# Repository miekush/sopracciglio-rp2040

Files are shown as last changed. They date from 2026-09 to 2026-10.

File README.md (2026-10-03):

# Sopracciglio RP2040
Raspberry Pi RP2040 based Sopracciglio Board for use with 2026 Open Sauce Badge

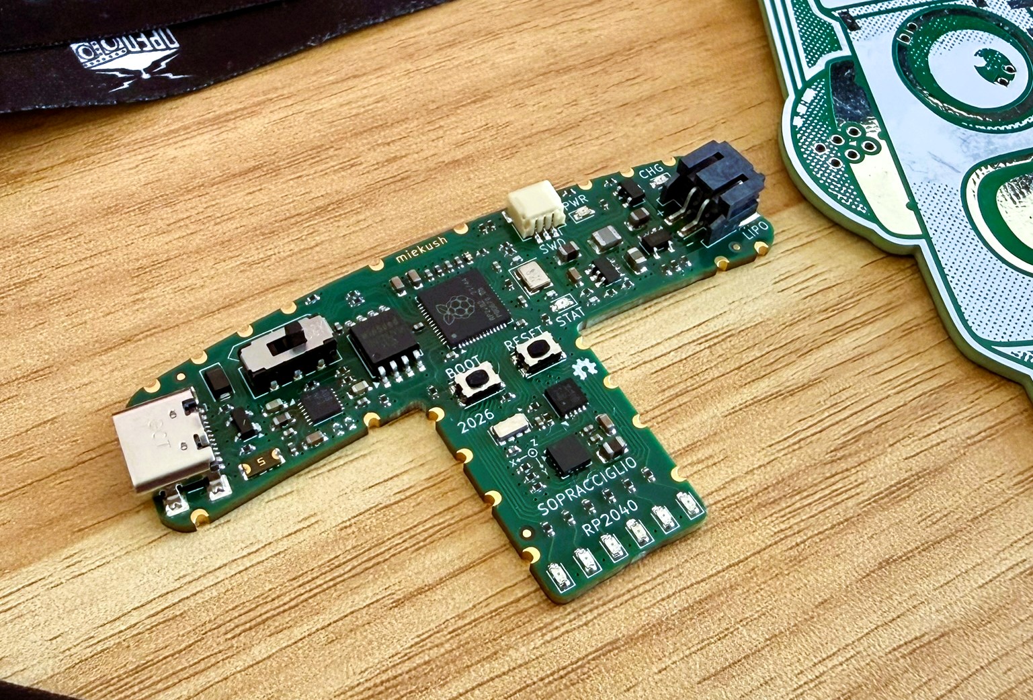
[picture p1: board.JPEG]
Board Image


# Schematic
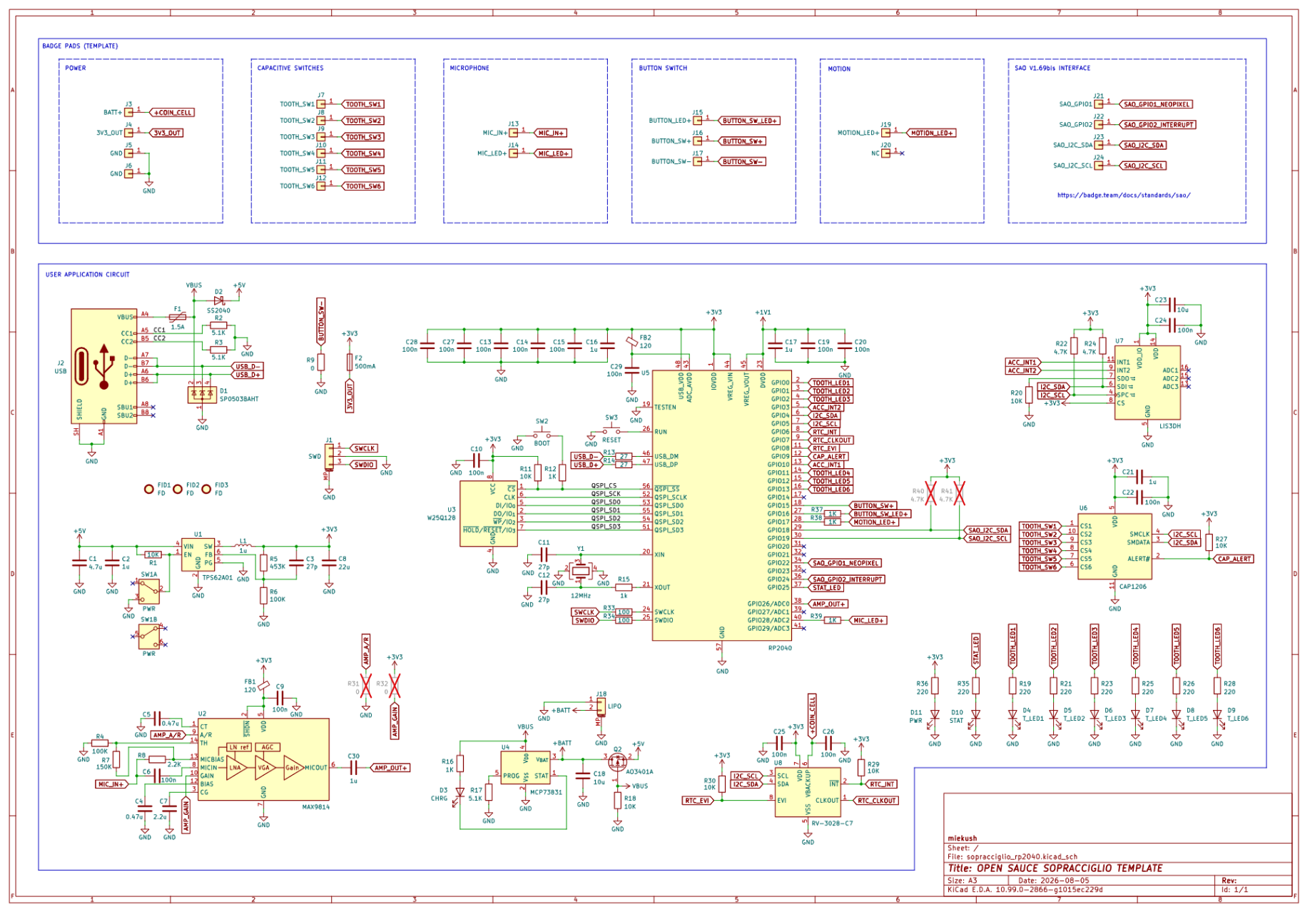
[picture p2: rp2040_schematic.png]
Schematic


# Layout
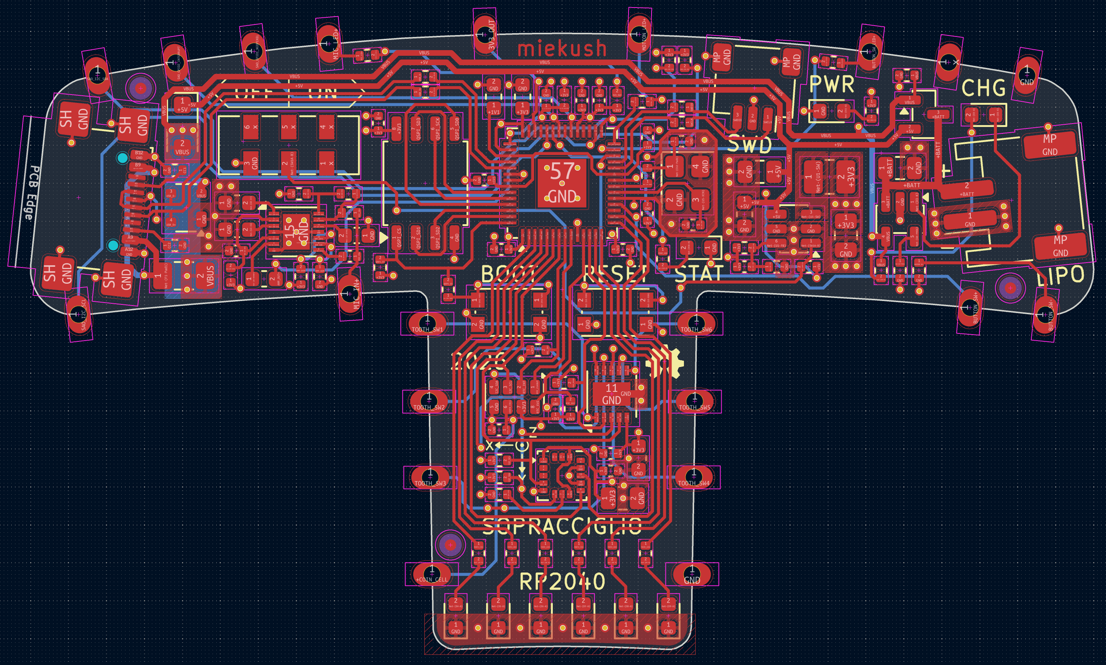
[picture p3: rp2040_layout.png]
Board Layout


# Installation

1. Clone repo to a folder of your choice
2. Open the project in KiCad V10.99
3. "Save As" with the name of your project
4. Enjoy! :)

# License

miekush supports the open source hardware community by sharing hardware design files freely on GitHub!

Designed by Mike Kushnerik (miekush)

Licensed under [Creative Commons Attribution-ShareAlike CC BY-SA 4.0](http://creativecommons.org/licenses/by-sa/4.0/)

All text above must be included in any redistribution!

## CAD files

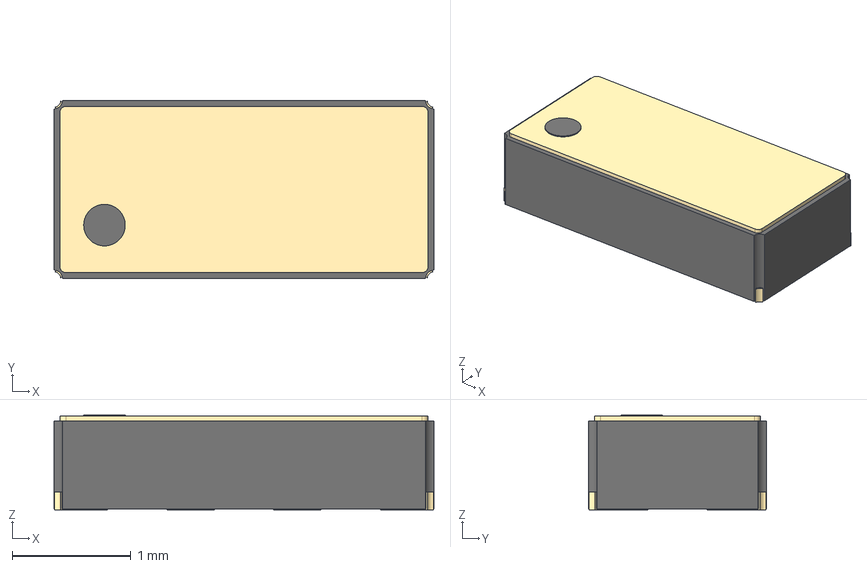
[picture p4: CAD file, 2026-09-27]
3D Models/RV-3028-C7.stp
3.20 x 1.50 x 0.8 mm
Rect2
Rect3
Rect4
Rect5
Terminal

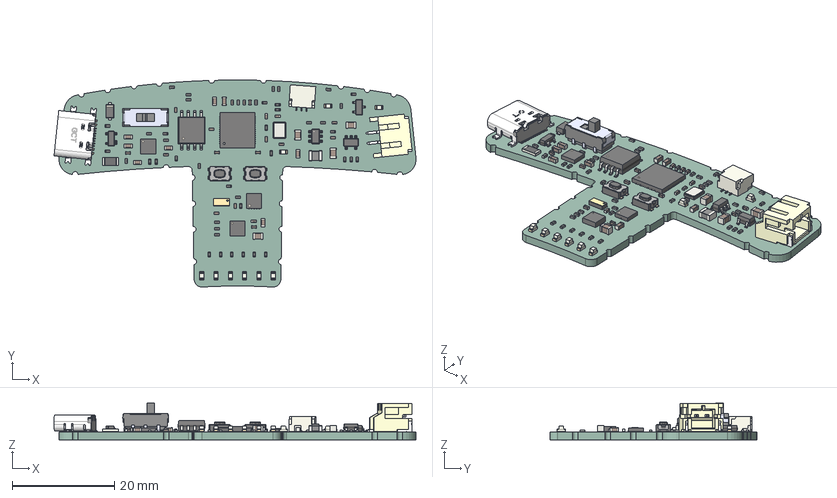
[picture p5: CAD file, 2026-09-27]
sopracciglio_rp2040.step
70.9 x 40.6 x 7.19 mm
C_0402_1005Metric x 19
R_0402_1005Metric x 41
LED_0603_1608Metric x 9
C_0603_1608Metric x 8
L_0402_1005Metric x 2
SOT-23
USB4110-GF-A_revB(1) MF
DFN-10-1EP_3x3mm_Pitch0.5mm
Crystal_SMD_Abracon_ABM8G-4Pin_3.2x2.5mm
S2B-PH-SM4-TB(LF)(SN)
C_0805_2012Metric x 4
SW_Push_1P1T_NO_CK_KMR2 x 2
JST_SH_SM03B-SRSS-TB_1x03-1MP_P1.00mm_Horizontal
LGA_16_3x3mm_P05mm_LayoutBorder3x5y
SOIC-8_5.3x5.3mm_P1.27mm
JS202011JCQN
SOT-23-6
Rect2
Rect3
Rect4
Rect5
Terminal
SOT-23-5
SOT-143
L_1008_2520Metric
DFN_14_1EP_3x3mm_Pitch04mm
D_SOD_123F
Fuse_1206_3216Metric
QFN-56-1EP_7x7mm_P0.4mm_EP3.2x3.2mm
sop3202_PCB

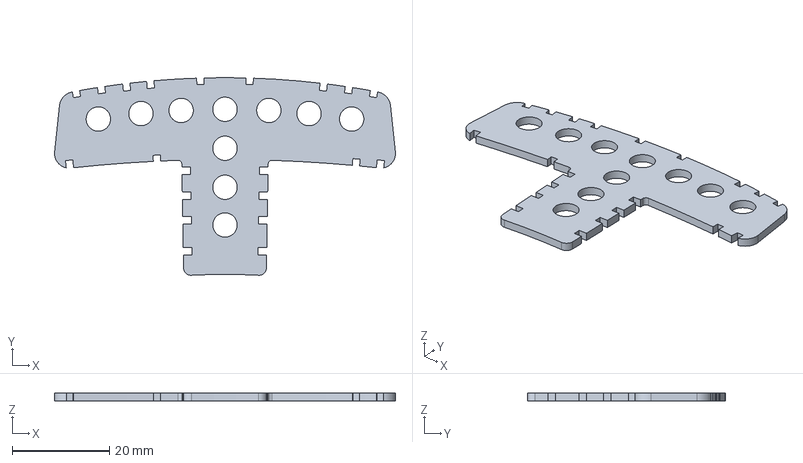
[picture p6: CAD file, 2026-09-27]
Board Outline/sopracciglio_outline.FCStd
70.0 x 40.6 x 1.60 mm

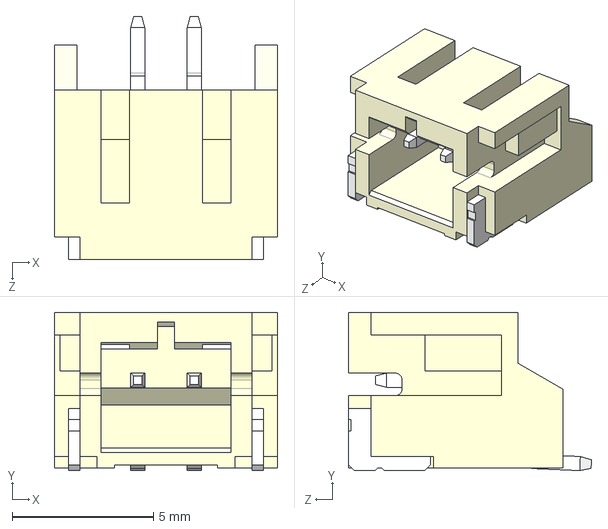
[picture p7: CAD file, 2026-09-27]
3D Models/S2B-PH-SM4-TB--3DModel-STEP-269445.STEP
7.90 x 5.60 x 8.60 mm

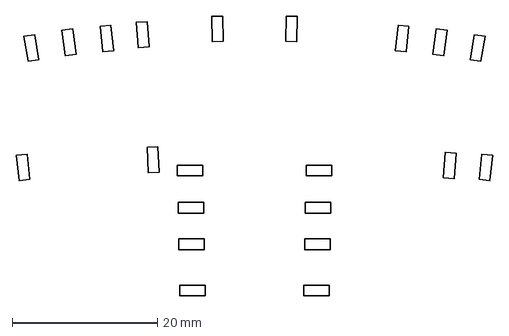
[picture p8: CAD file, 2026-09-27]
Board Outline/sopracciglio-pad_locations.dxf
65.5 x 38.5 mm

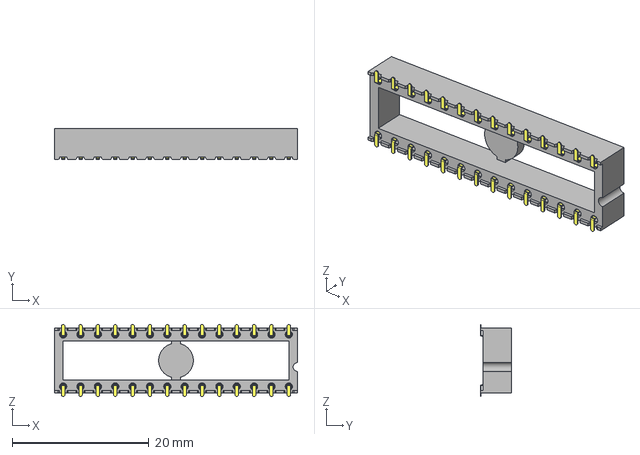
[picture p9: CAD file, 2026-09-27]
3D Models/ICF-328-T-O-TR.stp
35.6 x 4.57 x 10.5 mm
ICF-328-T-O-TR_t
ICF-328-O_p

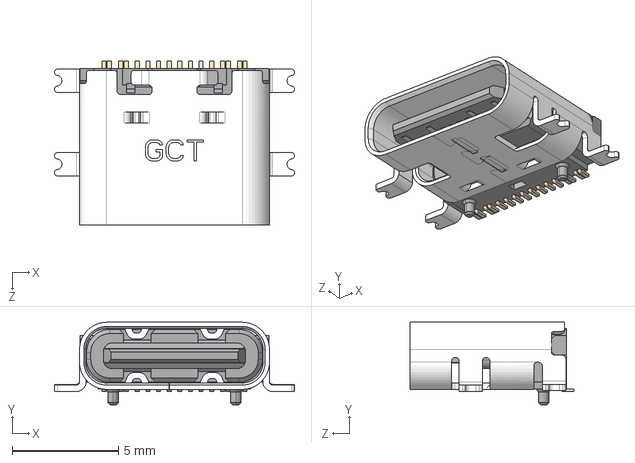
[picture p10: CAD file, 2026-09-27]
3D Models/USB4110GFA--3DModel-STEP-269445.STEP
11.3 x 3.89 x 7.70 mm

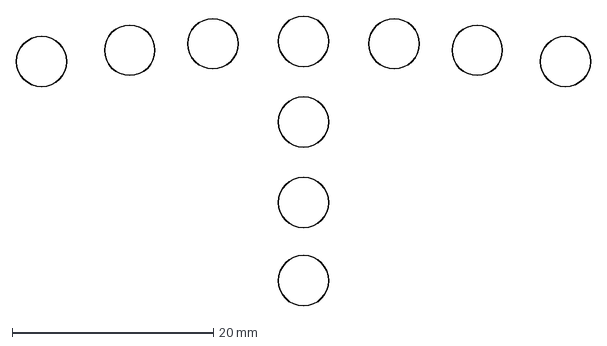
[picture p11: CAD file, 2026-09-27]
Board Outline/sopracciglio-bolts.dxf
57.0 x 28.8 mm

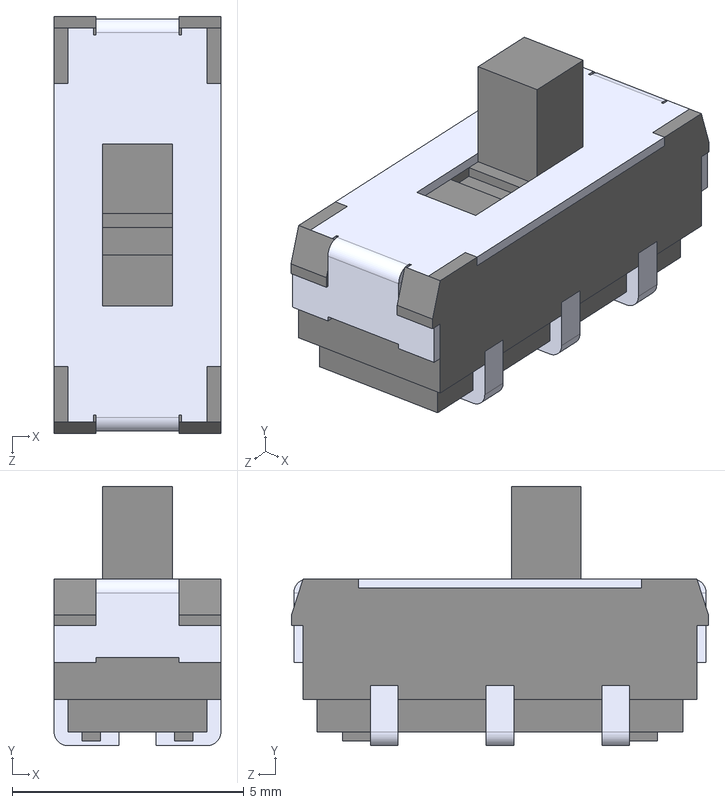
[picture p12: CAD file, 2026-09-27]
3D Models/JS202011JCQN--3DModel-STEP-1.STEP
3.60 x 5.60 x 9.00 mm

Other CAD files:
Board Outline/sopracciglio-outline.dxf

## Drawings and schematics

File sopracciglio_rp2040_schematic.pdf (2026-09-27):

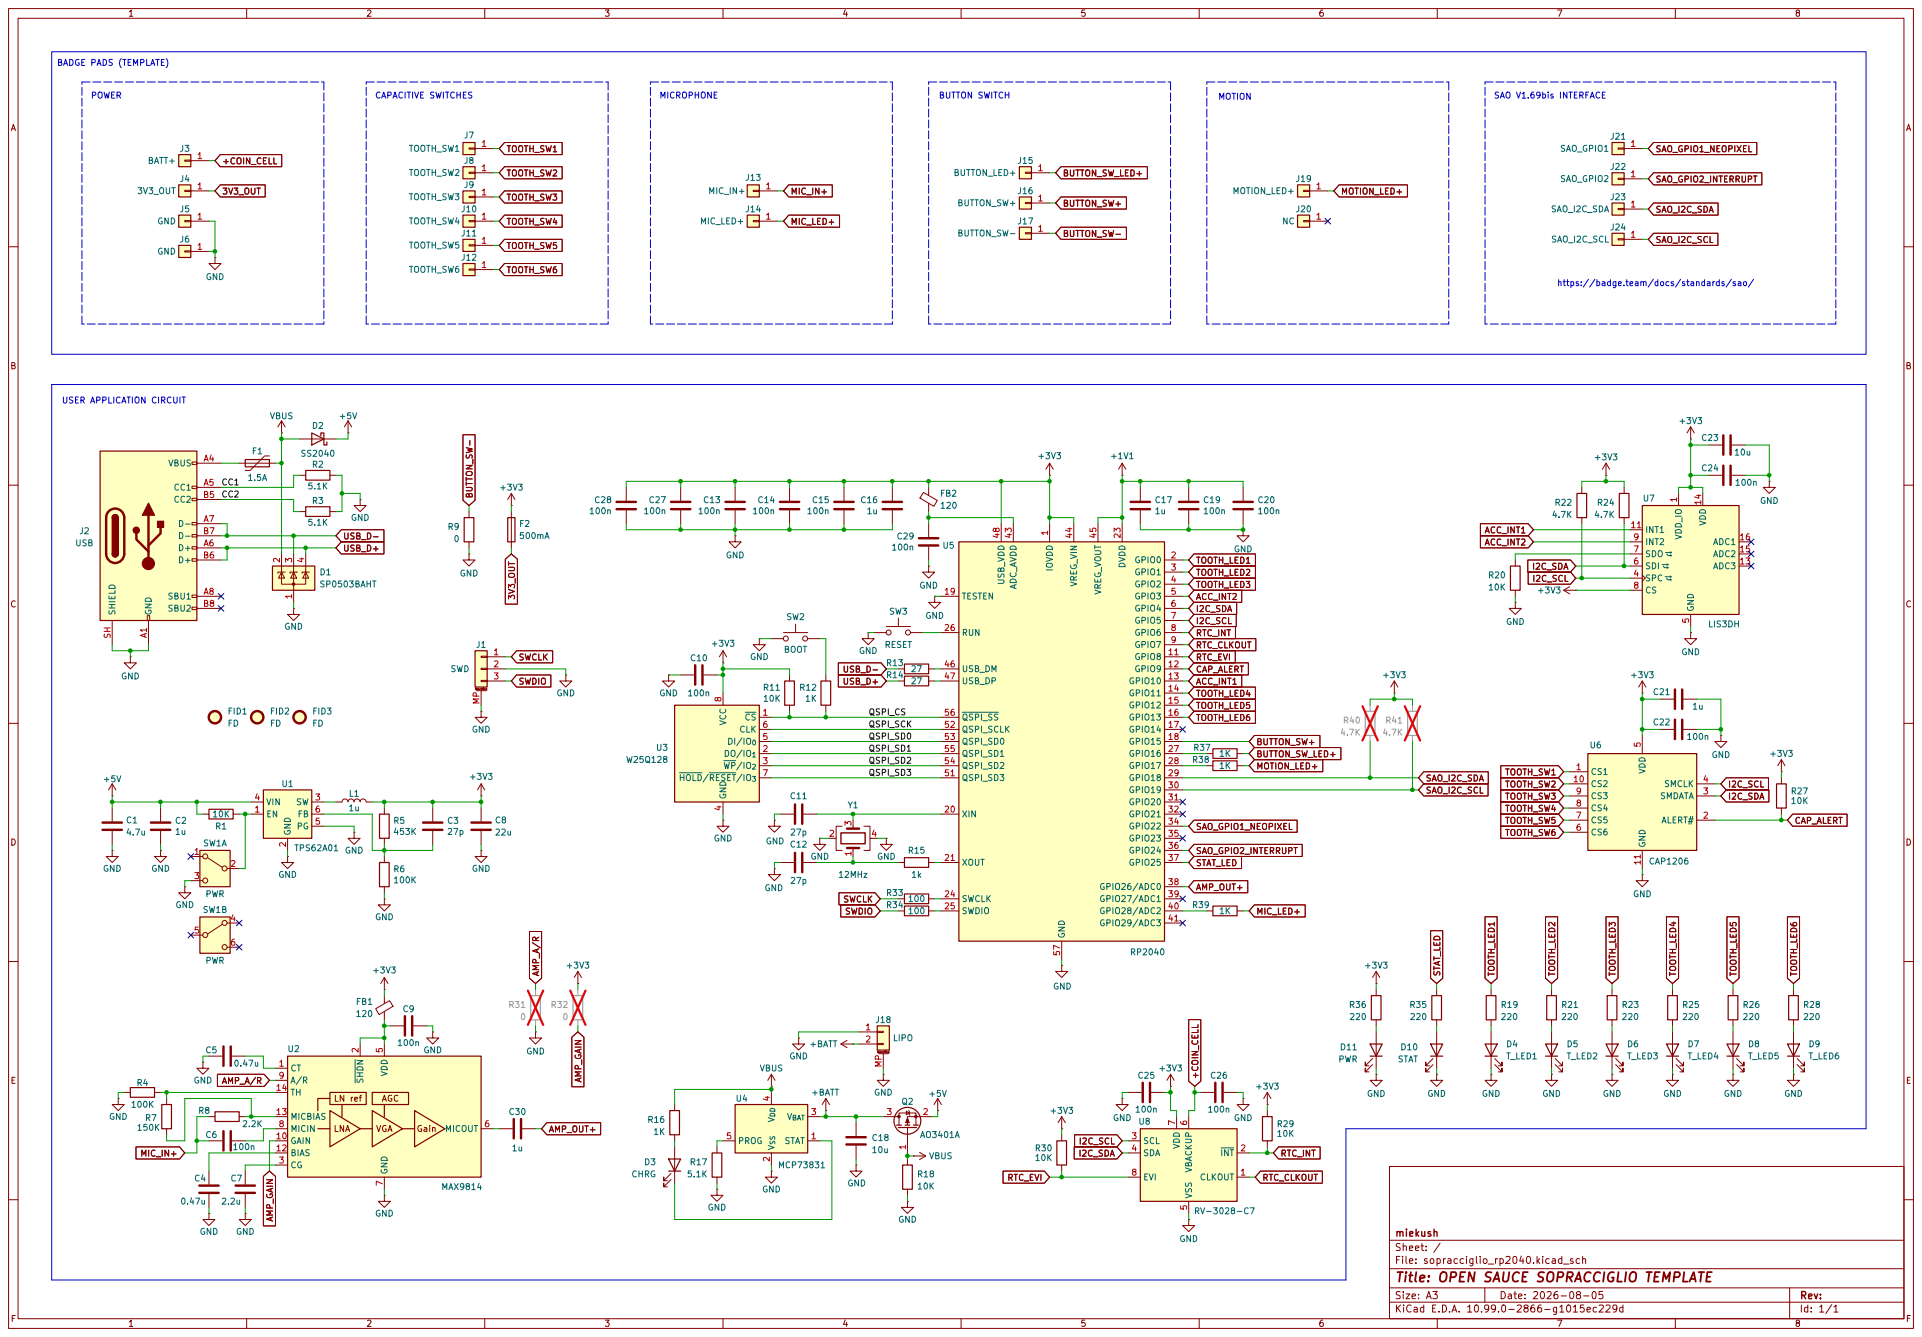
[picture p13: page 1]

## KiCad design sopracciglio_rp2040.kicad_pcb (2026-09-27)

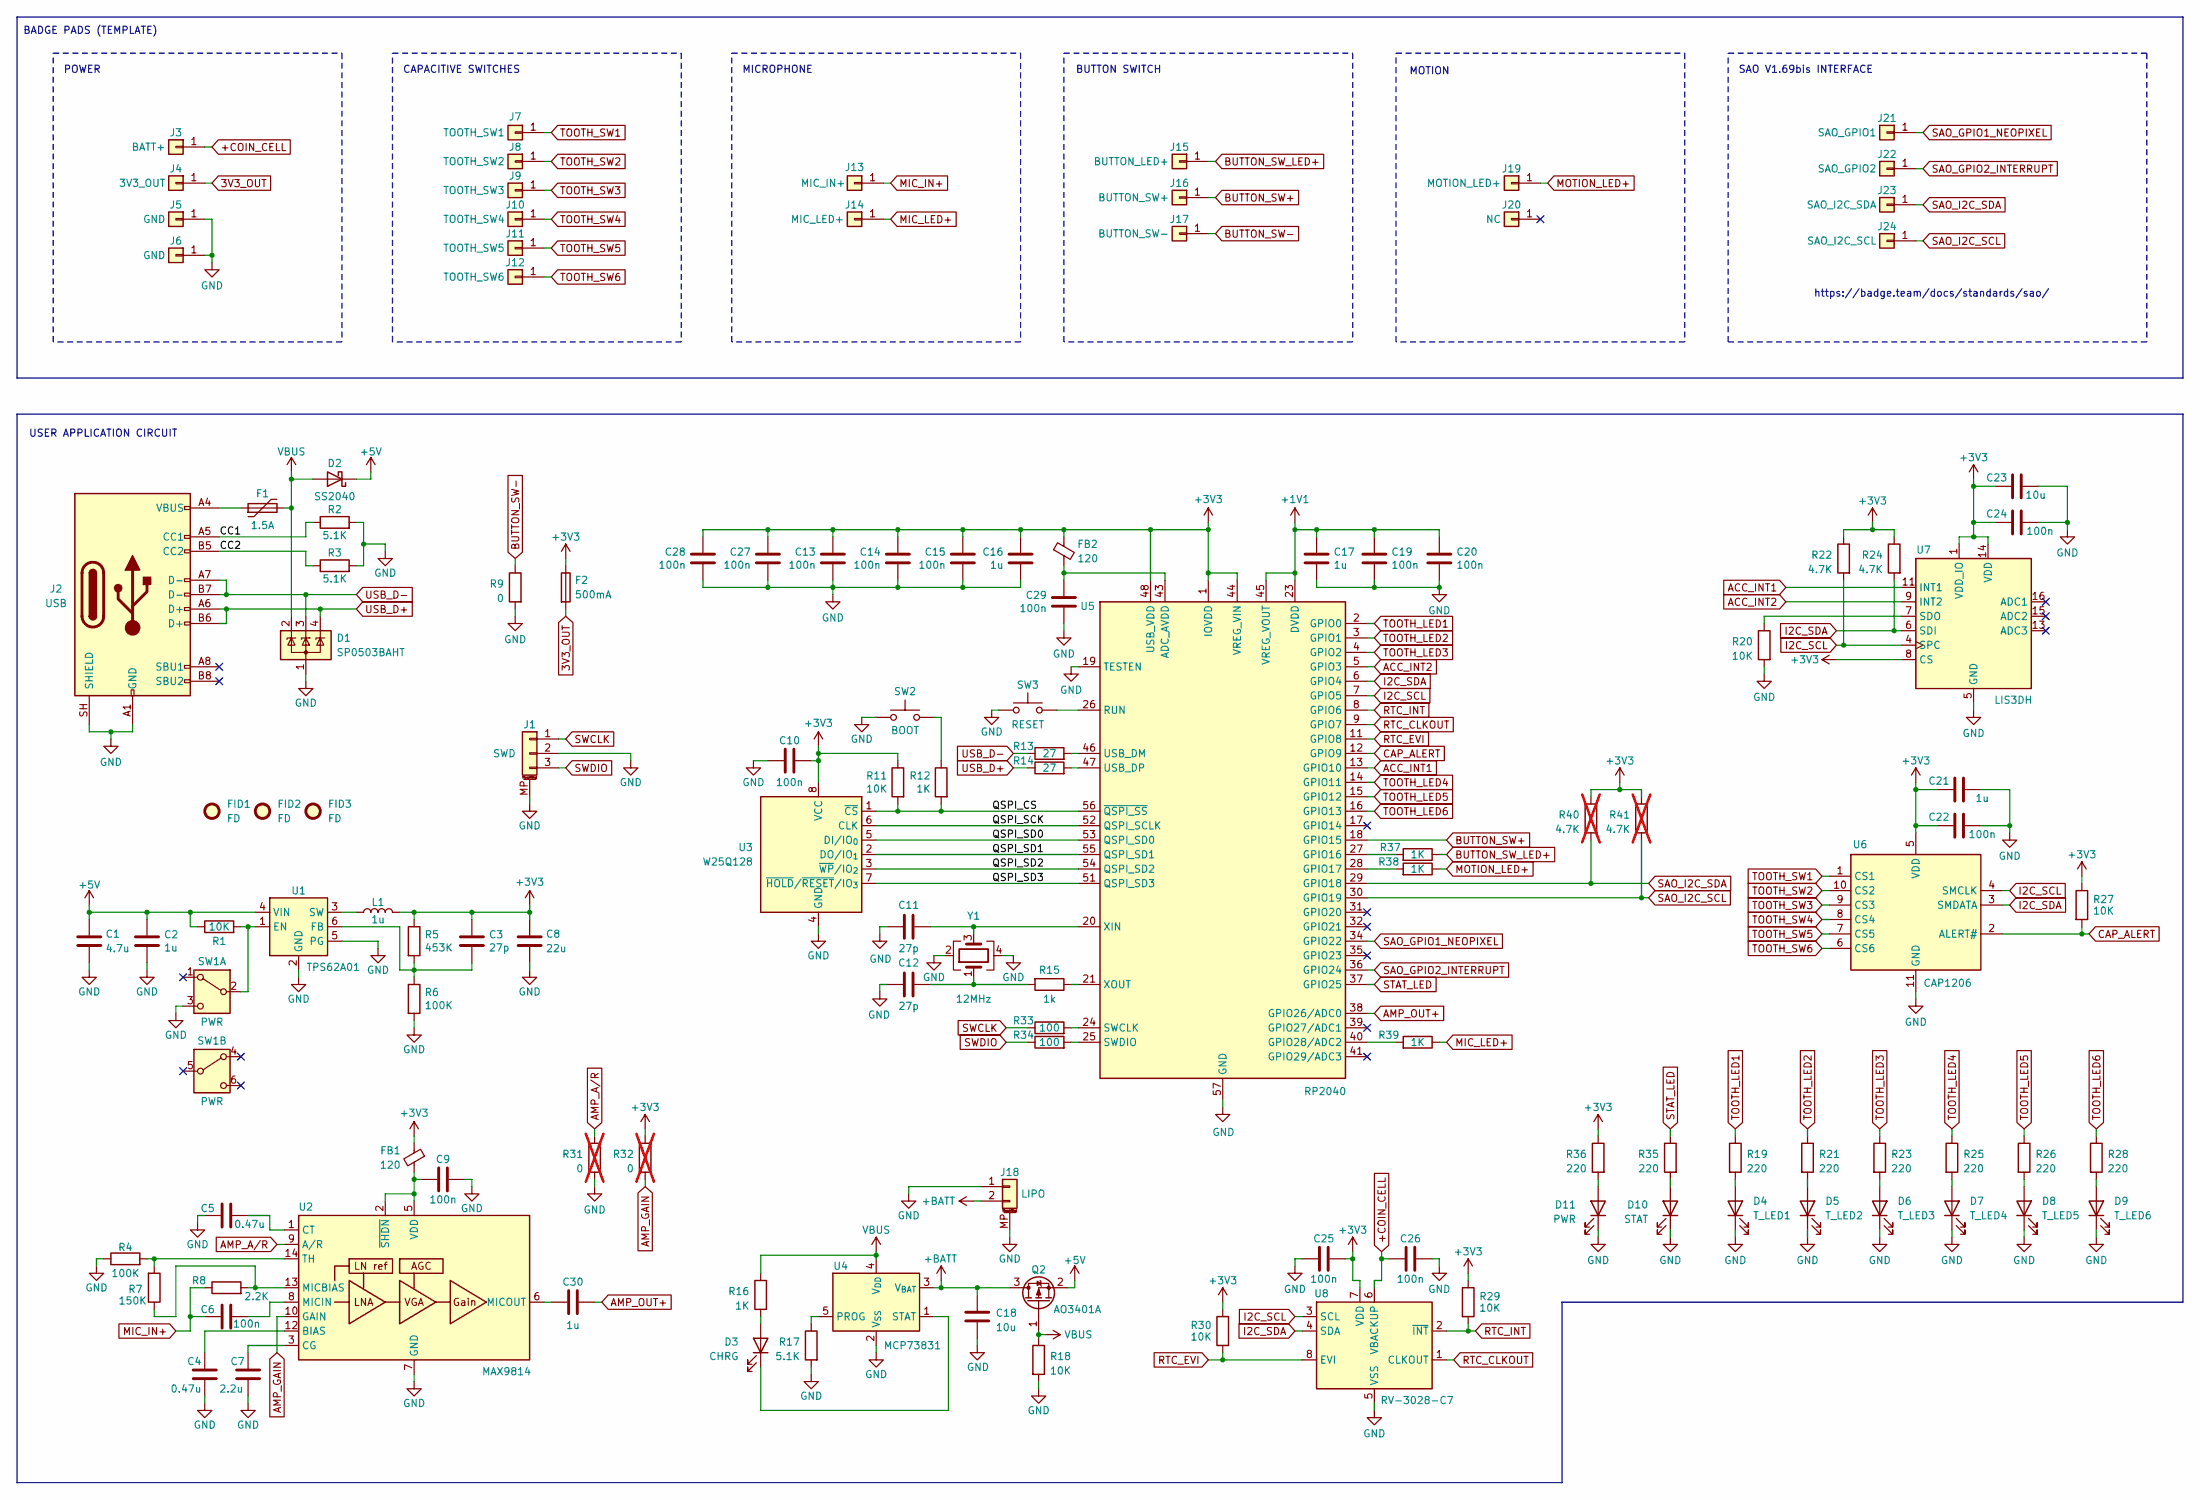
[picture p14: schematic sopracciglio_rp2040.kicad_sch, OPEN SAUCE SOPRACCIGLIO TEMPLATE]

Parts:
C1: 4.7u; C_0805_2012Metric
C2, C16, C17, C21, C30: 1u; C_0603_1608Metric
C3, C11, C12: 27p; C_0402_1005Metric
C4, C5: 0.47u; C_0603_1608Metric
C6, C9, C10, C13, C14, C15, C19, C20, C22, C24, C25, C26, C27, C28, C29: 100n; C_0402_1005Metric
C7: 2.2u; C_0603_1608Metric
C8: 22u; C_0805_2012Metric
C18, C23: 10u; C_0805_2012Metric
D1: SP0503BAHT; SOT-143
D2: SS2040; D_SOD-123F
D3: CHRG; LED_0603_1608Metric
D4: T_LED1; LED_0603_1608Metric
D5: T_LED2; LED_0603_1608Metric
D6: T_LED3; LED_0603_1608Metric
D7: T_LED4; LED_0603_1608Metric
D8: T_LED5; LED_0603_1608Metric
D9: T_LED6; LED_0603_1608Metric
D10: STAT; LED_0603_1608Metric
D11: PWR; LED_0603_1608Metric
F1: 1.5A; Fuse_1206_3216Metric
F2: 500mA; Fuse_0402_1005Metric
FB1, FB2: 120; L_0402_1005Metric
FID1, FID2, FID3: FD; Fiducial_0.75mm_Mask1.5mm
J1: SWD; JST_SH_SM03B-SRSS-TB_1x03-1MP_P1.00mm_Horizontal
J2: USB; USB_C_Receptacle_GCT_USB4110
J3: BATT+; castellated_pad
J4: 3V3_OUT; castellated_pad
J5, J6: GND; castellated_pad
J7: TOOTH_SW1; castellated_pad
J8: TOOTH_SW2; castellated_pad
J9: TOOTH_SW3; castellated_pad
J10: TOOTH_SW4; castellated_pad
J11: TOOTH_SW5; castellated_pad
J12: TOOTH_SW6; castellated_pad
J13: MIC_IN+; castellated_pad
J14: MIC_LED+; castellated_pad
J15: BUTTON_LED+; castellated_pad
J16: BUTTON_SW+; castellated_pad
J17: BUTTON_SW-; castellated_pad
J18: LIPO; JST_PH_S2B-PH-SM4-TB_1x02-1MP_P2.00mm_Horizontal
J19: MOTION_LED+; castellated_pad
J20: NC; castellated_pad
J21: SAO_GPIO1; castellated_pad
J22: SAO_GPIO2; castellated_pad
J23: SAO_I2C_SDA; castellated_pad
J24: SAO_I2C_SCL; castellated_pad
L1: 1u; L_1008_2520Metric
Q2: AO3401A; SOT-23
R1, R11, R18, R20, R27, R29, R30: 10K; R_0402_1005Metric
R2, R3, R17: 5.1K; R_0402_1005Metric
R4, R6: 100K; R_0402_1005Metric
R5: 453K; R_0402_1005Metric
R7: 150K; R_0402_1005Metric
R8: 2.2K; R_0402_1005Metric
R9: 0; R_0402_1005Metric
R12, R16, R37, R38, R39: 1K; R_0402_1005Metric
R13, R14: 27; R_0402_1005Metric
R15: 1k; R_0402_1005Metric
R19, R21, R23, R25, R26, R28, R35, R36: 220; R_0402_1005Metric
R22, R24: 4.7K; R_0402_1005Metric
R31, R32: 0; R_0402_1005Metric; not fitted
R33, R34: 100; R_0402_1005Metric
R40, R41: 4.7K; R_0402_1005Metric; not fitted
SW1: PWR; SW_DPDT_CK_JS202011JCQN
SW2: BOOT; SW_Push_1P1T_NO_CK_KMR2
SW3: RESET; SW_Push_1P1T_NO_CK_KMR2
U1: TPS62A01; SOT-23-6
U2: MAX9814; DFN-14-1EP_3x3mm_P0.4mm_EP1.78x2.35mm
U3: W25Q128; SOIC-8_5.3x5.3mm_P1.27mm
U4: MCP73831; SOT-23-5
U5: RP2040; QFN-56-1EP_7x7mm_P0.4mm_EP3.2x3.2mm
U6: CAP1206; DFN-10-1EP_3x3mm_P0.5mm_EP1.55x2.48mm
U7: LIS3DH; LGA-16_3x3mm_P0.5mm_LayoutBorder3x5y
U8: RV-3028-C7; MicroCrystal_C7_SON-8_1.5x3.2mm_P0.9mm
Y1: 12MHz; Crystal_SMD_Abracon_ABM8G-4Pin_3.2x2.5mm

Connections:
3V3_OUT: F2.2, J4.1 (Pin_1_1)
+1V1: C17.1, C19.1, C20.1, U5.23 (DVDD), U5.45 (VREG_VOUT), U5.50 (DVDD)
+3V3: C3.1, C8.1, C10.1, C13.1, C14.1, C15.1, C16.1, C21.1, C22.1, C23.1, C24.1, C25.1, C27.1, C28.1, F2.1, FB1.1, FB2.1, L1.2, R5.1, R11.1, R22.1, R24.1, R27.1, R29.1, R30.1, R32.1, R36.1, R40.1, R41.1, U3.8 (VCC), U5.1 (IOVDD), U5.10 (IOVDD), U5.22 (IOVDD), U5.33 (IOVDD), U5.42 (IOVDD), U5.44 (VREG_VIN), U5.48 (USB_VDD), U5.49 (IOVDD), U6.5 (VDD), U7.1 (VDD_IO), U7.8 (CS), U7.14 (VDD), U8.7 (VDD)
+5V: C1.1, C2.1, D2.1 (K), Q2.2 (S), R1.1, U1.4 (VIN)
+BATT: C18.1, J18.2, Q2.3 (D), U4.3 (V_{BAT})
+COIN_CELL: C26.1, J3.1 (Pin_1_1), U8.6 (VBACKUP)
/CC1: J2.A5 (CC1), R2.1
/CC2: J2.B5 (CC2), R3.1
/QSPI_CS: R11.2, R12.2, U3.1 (~CS), U5.56 (~QSPI_SS)
/QSPI_SCK: U3.6 (CLK), U5.52 (QSPI_SCLK)
/QSPI_SD0: U3.5 (DI/IO_{0}), U5.53 (QSPI_SD0)
/QSPI_SD1: U3.2 (DO/IO_{1}), U5.55 (QSPI_SD1)
/QSPI_SD2: U3.3 (~WP/IO_{2}), U5.54 (QSPI_SD2)
/QSPI_SD3: U3.7 (~HOLD/~RESET/IO_{3}), U5.51 (QSPI_SD3)
ACC_INT1: U5.13 (GPIO10), U7.11 (INT1)
ACC_INT2: U5.5 (GPIO3), U7.9 (INT2)
AMP_A/R: R31.1, U2.9 (A/R)
AMP_GAIN: R32.2, U2.10 (GAIN)
AMP_OUT+: C30.2, U5.38 (GPIO26/ADC0)
BUTTON_SW+: J16.1 (Pin_1_1), U5.18 (GPIO15)
BUTTON_SW-: J17.1 (Pin_1_1), R9.1
BUTTON_SW_LED+: J15.1 (Pin_1_1), R37.1
CAP_ALERT: R27.2, U5.12 (GPIO9), U6.2 (ALERT#)
GND: C1.2, C2.2, C4.1, C5.1, C7.1, C8.2, C9.2, C10.2, C11.2, C12.2, C13.2, C14.2, C15.2, C16.2, C17.2, C18.2, C19.2, C20.2, C21.2, C22.2, C23.2, C24.2, C25.2, C26.2, C27.2, C28.2, C29.2, D1.1 (A), D4.1 (K), D5.1 (K), D6.1 (K), D7.1 (K), D8.1 (K), D9.1 (K), D10.1 (K), D11.1 (K), J1.2, J1.MP (MountPin), J2.A1 (GND), J2.A12 (GND), J2.B1 (GND), J2.B12 (GND), J2.SH (SHIELD), J5.1 (Pin_1_1), J6.1 (Pin_1_1), J18.1, J18.MP (MountPin), R2.2, R3.2, R4.1, R6.2, R9.2, R17.2, R18.2, R20.2, R31.2, SW1.3 (C), SW2.2, SW3.1, U1.2 (GND), U1.5 (PG), U2.4 (GND), U2.7 (GND), U2.11 (GND), U2.15 (GND), U3.4 (GND), U4.2 (V_{SS}), U5.19 (TESTEN), U5.57 (GND), U6.11 (GND), U7.5 (GND), U7.10 (GND), U7.12 (GND), U8.5 (VSS), Y1.2, Y1.4
I2C_SCL: R22.2, U5.7 (GPIO5), U6.4 (SMCLK), U7.4 (SPC), U8.3 (SCL)
I2C_SDA: R24.2, U5.6 (GPIO4), U6.3 (SMDATA), U7.6 (SDI), U8.4 (SDA)
MIC_IN+: C6.1, J13.1 (Pin_1_1), R8.1
MIC_LED+: J14.1 (Pin_1_1), R39.1
MOTION_LED+: J19.1 (Pin_1_1), R38.1
unnamed: C12.1, R15.2, Y1.1
unnamed: D3.2 (A), R16.2
unnamed: D3.1 (K), U4.1 (STAT)
unnamed: D4.2 (A), R19.2
unnamed: D5.2 (A), R21.2
unnamed: D6.2 (A), R23.2
unnamed: D7.2 (A), R25.2
unnamed: D8.2 (A), R26.2
unnamed: D9.2 (A), R28.2
unnamed: D10.2 (A), R35.2
unnamed: D11.2 (A), R36.2
unnamed: F1.1, J2.A4 (VBUS), J2.A9 (VBUS), J2.B4 (VBUS), J2.B9 (VBUS)
unnamed: R12.1, SW2.1
unnamed: R1.2, SW1.2 (B), U1.1 (EN)
unnamed: C3.2, R5.2, R6.1, U1.6 (FB)
unnamed: L1.1, U1.3 (SW)
unnamed: C4.2, U2.12 (BIAS)
unnamed: C7.2, U2.3 (CG)
unnamed: C5.2, U2.1 (CT)
unnamed: R7.1, R8.2, U2.13 (MICBIAS)
unnamed: C6.2, U2.8 (MICIN)
unnamed: C30.1, U2.6 (MICOUT)
unnamed: R4.2, R7.2, U2.14 (TH)
unnamed: C9.1, FB1.2, U2.2 (~SHDN), U2.5 (VDD)
unnamed: R17.1, U4.5 (PROG)
unnamed: C29.1, FB2.2, U5.43 (ADC_AVDD)
unnamed: R37.2, U5.27 (GPIO16)
unnamed: R38.2, U5.28 (GPIO17)
unnamed: R39.2, U5.40 (GPIO28/ADC2)
unnamed: SW3.2, U5.26 (RUN)
unnamed: R33.2, U5.24 (SWCLK)
unnamed: R34.2, U5.25 (SWDIO)
unnamed: R13.2, U5.46 (USB_DM)
unnamed: R14.2, U5.47 (USB_DP)
unnamed: C11.1, U5.20 (XIN), Y1.3
unnamed: R15.1, U5.21 (XOUT)
unnamed: R20.1, U7.7 (SDO)
RTC_CLKOUT: U5.9 (GPIO7), U8.1 (CLKOUT)
RTC_EVI: R30.2, U5.11 (GPIO8), U8.8 (EVI)
RTC_INT: R29.2, U5.8 (GPIO6), U8.2 (~INT)
SAO_GPIO1_NEOPIXEL: J21.1 (Pin_1_1), U5.34 (GPIO22)
SAO_GPIO2_INTERRUPT: J22.1 (Pin_1_1), U5.36 (GPIO24)
SAO_I2C_SCL: J24.1 (Pin_1_1), R41.2, U5.30 (GPIO19)
SAO_I2C_SDA: J23.1 (Pin_1_1), R40.2, U5.29 (GPIO18)
STAT_LED: R35.1, U5.37 (GPIO25)
SWCLK: J1.1, R33.1
SWDIO: J1.3, R34.1
TOOTH_LED1: R19.1, U5.2 (GPIO0)
TOOTH_LED2: R21.1, U5.3 (GPIO1)
TOOTH_LED3: R23.1, U5.4 (GPIO2)
TOOTH_LED4: R25.1, U5.14 (GPIO11)
TOOTH_LED5: R26.1, U5.15 (GPIO12)
TOOTH_LED6: R28.1, U5.16 (GPIO13)
TOOTH_SW1: J7.1 (Pin_1_1), U6.1 (CS1)
TOOTH_SW2: J8.1 (Pin_1_1), U6.10 (CS2)
TOOTH_SW3: J9.1 (Pin_1_1), U6.9 (CS3)
TOOTH_SW4: J10.1 (Pin_1_1), U6.8 (CS4)
TOOTH_SW5: J11.1 (Pin_1_1), U6.7 (CS5)
TOOTH_SW6: J12.1 (Pin_1_1), U6.6 (CS6)
USB_D+: D1.4 (K), J2.A6 (D+), J2.B6 (D+), R14.1
USB_D-: D1.3 (K), J2.A7 (D-), J2.B7 (D-), R13.1
VBUS: D1.2 (K), D2.2 (A), F1.2, Q2.1 (G), R16.1, R18.1, U4.4 (V_{DD})

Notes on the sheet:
SAO V1.69bis INTERFACE
https://badge.team/docs/standards/sao/
CAPACITIVE SWITCHES
BUTTON SWITCH
POWER
USER APPLICATION CIRCUIT
MOTION
MICROPHONE
BADGE PADS (TEMPLATE)

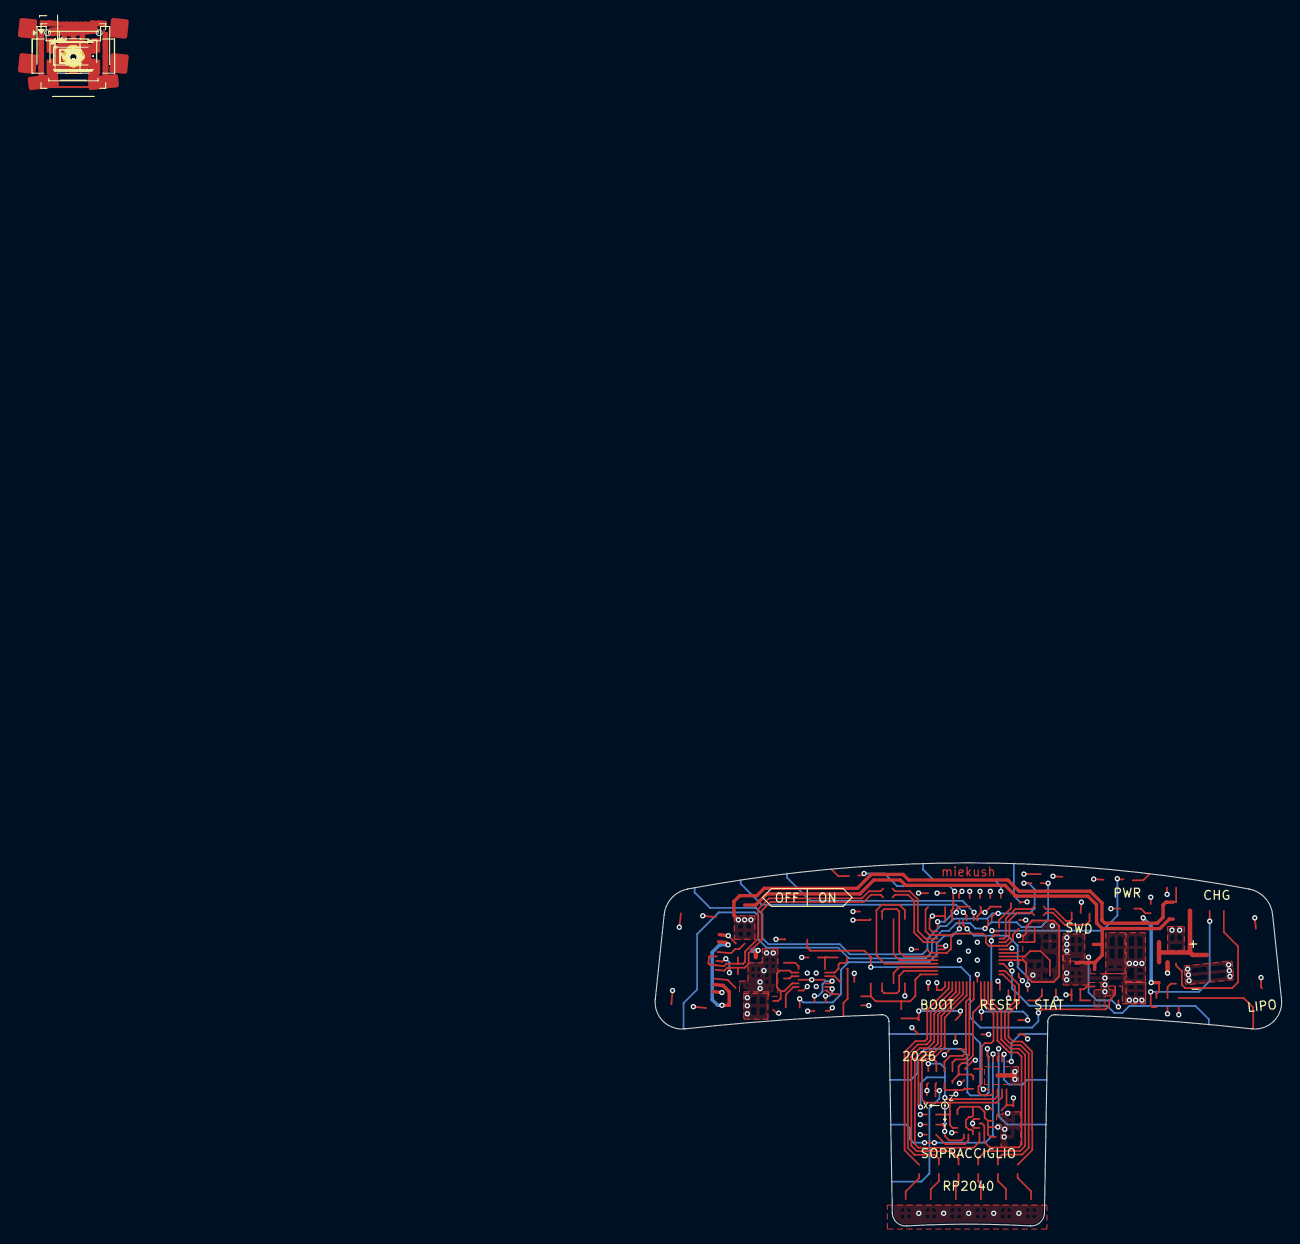
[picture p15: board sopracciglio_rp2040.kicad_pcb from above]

Board: 4 copper layers, 70.0 x 40.6 mm, 126 parts (0 on the bottom side), 91 nets.

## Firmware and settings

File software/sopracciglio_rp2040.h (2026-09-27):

//sopracciglio_rp2040.h
//author: mike kushnerik
//date: 9/25/2026

#ifndef _SOPRACCIGLIO_RP2040_H_
#define _SOPRACCIGLIO_RP2040_H_

#include <Arduino.h>

#ifdef __cplusplus
extern "C" {
#endif

//onboard i2c bus for rtc, cap touch controller, and accelerometer
#define I2C0_SDA        4
#define I2C0_SCL        5

//i2c addresses
#define CAP1206_ADDR    0x28
#define LIS3DH_ADDR     0x30
#define RV3028_ADDR     0x52

//cap1206 registers
#define CAP1206_MAIN_CONTROL          0x00
#define CAP1206_GENERAL_STATUS        0x02
#define CAP1206_SENSOR_INPUT_STATUS   0x03

//tooth leds
#define T_LED_1         0
#define T_LED_2         1
#define T_LED_3         2
#define T_LED_4         11
#define T_LED_5         12
#define T_LED_6         13

//accelerometer pins
#define ACC_INT1        10
#define ACC_INT2        3

//rtc pins
#define RTC_INT         6
#define RTC_CLKOUT      7
#define RTC_EVI         8

//cap touch pins
#define CAP_ALERT       9

//sao pins
#define SAO_GPIO1       22
#define SAO_GPIO2       24
#define SAO_I2C_SDA     18
#define SAO_I2C_SCL     19

//onboard leds
#define STAT_LED        25

//microphone
#define MIC_AUDIO_IN    26

/// badge i/o ///

//button switch
#define BUTTON_SW       15
#define BUTTON_SW_LED   16

//motion
#define MOTION_LED      17

//microphone
#define MIC_LED         28

//function prototypes
void sopracciglio_rp2040_init(void);

#ifdef __cplusplus
}
#endif

#endif

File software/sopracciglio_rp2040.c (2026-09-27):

//sopracciglio_rp2040.c
//author: mike kushnerik
//date: 9/25/2026

#include "sopracciglio_rp2040.h"

void sopracciglio_rp2040_init(void)
{
  //tooth leds
  pinMode(T_LED_1, OUTPUT);
  pinMode(T_LED_2, OUTPUT);
  pinMode(T_LED_3, OUTPUT);
  pinMode(T_LED_4, OUTPUT);
  pinMode(T_LED_5, OUTPUT);
  pinMode(T_LED_6, OUTPUT);
  digitalWrite(T_LED_1, LOW);
  digitalWrite(T_LED_2, LOW);
  digitalWrite(T_LED_3, LOW);
  digitalWrite(T_LED_4, LOW);
  digitalWrite(T_LED_5, LOW);
  digitalWrite(T_LED_6, LOW);

  //acc
  pinMode(ACC_INT1, INPUT);
  pinMode(ACC_INT2, INPUT);

  //rtc
  pinMode(RTC_INT, INPUT);
  pinMode(RTC_CLKOUT, INPUT);
  pinMode(RTC_EVI, OUTPUT);
  digitalWrite(RTC_EVI, LOW);

  //cap
  pinMode(CAP_ALERT, INPUT);

  //sao
  pinMode(SAO_GPIO1, OUTPUT);
  pinMode(SAO_GPIO2, OUTPUT);
  digitalWrite(SAO_GPIO1, LOW);
  digitalWrite(SAO_GPIO2, LOW);

  //stat led
  pinMode(STAT_LED, OUTPUT);

  //button switch
  pinMode(BUTTON_SW, INPUT_PULLUP);
  pinMode(BUTTON_SW_LED, OUTPUT);

  //motion
  pinMode(MOTION_LED, OUTPUT);

  //mic
  pinMode(MIC_LED, OUTPUT);
}

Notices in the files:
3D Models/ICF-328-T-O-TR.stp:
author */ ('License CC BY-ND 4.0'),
